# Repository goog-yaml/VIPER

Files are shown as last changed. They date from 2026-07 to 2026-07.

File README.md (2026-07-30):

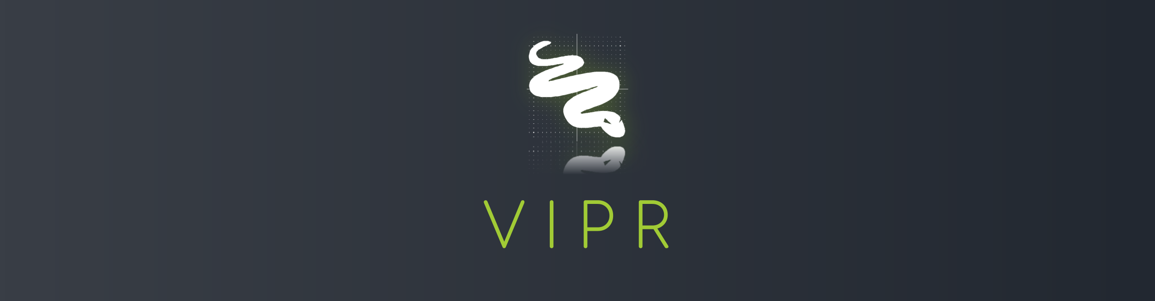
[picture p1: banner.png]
banner


# What is VIPR?

Simply put, VIPR is a open source radio node designed and built around North American mesh communication over LoRa built off of an ESP32-S3 platform. Put less simply, VIPR is another ESP32 development board focused more on frontend, hardware, and size. The project aims to create a small, pocketable radio node that can run independently. Currently the procsessing power of it's latest version (2.0) can only handle small workloads and can only run a Real Time OS in comparison to a fully fledged computer.

**VIPR is currently in Alpha testing, soon to be beta!**

## Current Revision

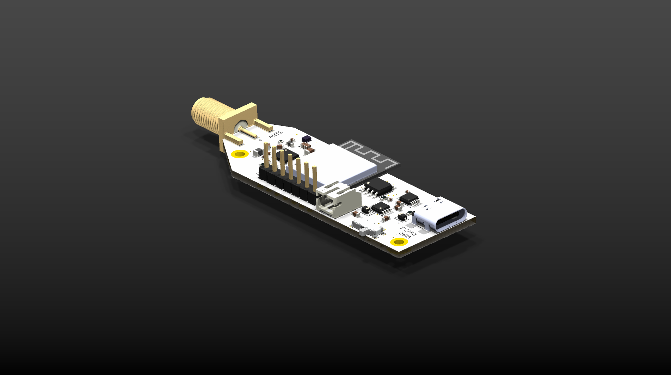
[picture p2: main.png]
Render1


Currently the board packs a 19mm wide footprint without a screen. The end is equipped with an SMA conector for easy antenna swaps and the side boasts an onboard PCB wifi antenna tied to the ESP32-MINI-1 module.

Future revisions intend to add a screen and interactives to the board to further refine the frontend, all that is needed after that is software and a case!

### Changelog

```
* Redid a proper BOM
    * This included sizing and components selection
* Added back the CH340X
* Reverted to old "pen" form factor
* Created a new "lopsided" board end 
* Added a screen header
* Fixed a regulator issue on the radio portion
* bundled CAD files into production folders <=2.1
```

## Docs

Docs will be coming soon!
<br>

## Versioning system

The project follows a versioning system of major and minor. The first number in the version is the board platform. Whenever the board is fully redone a new major version will be released. Whenever the board has a small tweak to an existing platform version the second number behind the first will be bumped up by one.

A board version of say, 2.1 would indicate platform version 2 with one tweak of the original version 2.0.

#### Latest Journal as of July 28th

For revision 2.1. I introduced a versioning system of major and minor.
 What's new in 2.1?

Mounting holes for M2 screws on the left side of the board and a header connection for a screen. the schematics now include test points for serial, power, and JTAG soon to be onboard for revision 2.2.

Some issues were included in revision 2 that would prevent stable operation of the radio caused by a faulty connection between the regulator for the SX1262 and the inductor managing it.

That's all.

-Matias

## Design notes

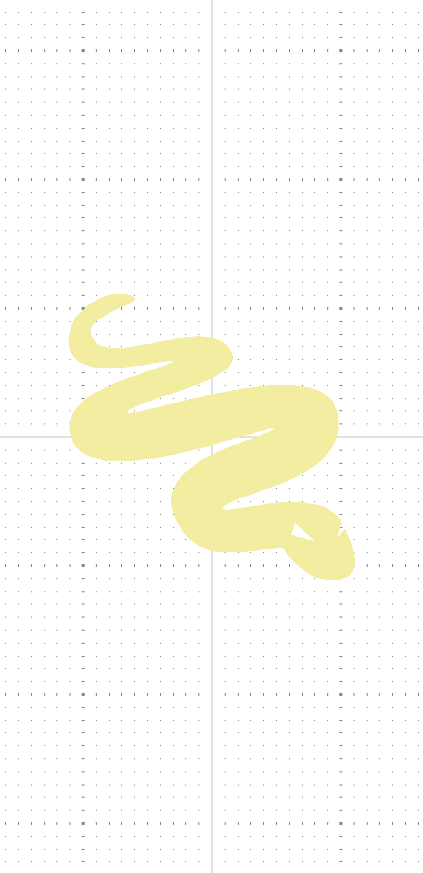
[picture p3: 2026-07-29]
KiCAD/main/viper.png

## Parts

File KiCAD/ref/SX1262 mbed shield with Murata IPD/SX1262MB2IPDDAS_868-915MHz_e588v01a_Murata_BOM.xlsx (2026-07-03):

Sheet: SX1262MB2IPDDAS
 |  |  | SX1262MB2IPDDAS mbed shield with IPD filter BOM - 868/915MHz |  |  | BOM # V1a
 |  |  |  |  |  | SCH # e588v01a
 |  |  | 2025-11-11 | EMr | Version e588v01a | PCB # e588v01a
RefDes | MPN | Geom | Value | Qty | Description | Manufacturer
U1 | SX1262IMLTRT | VQFN24 4x4mm | SX1262 | 1 | 150MHz to 960MHz Low Power Long Range Transceiver | Semtech
U2 | BGS12WN6 | PG-TSNP-6-10 | - | 1 | Wideband SPDT Diversity Switch with Fast Switching Speed | Infineon
U3 | LFB21892MDZ7F957 | 2.00x1.25mm | 868/915MHz | 1 | 868/915MHz Miniature Impedance-matched Filter for SX1261/62 and LLCC68 optimized for US and EU +22 dBm Operation | Murata
Resistors
R1 | CRCW06030000Z0EAHP | 0603 | 0R | 1 | Thick Film Resistor ±1%, 1/4W | Vishay/Dale
R2 | CRCW06030000Z0EAHP | 0603 | 0R | 1 | Thick Film Resistor ±1%, 1/4W | Vishay/Dale
R3 | CRCW0201100RJNED | 0201 | 100R | 1 | Thick Film Resistor ±5%, 1/20W | Vishay/Dale
R4 | CRCW0201100RJNED | 0201 | 100R | 1 | Thick Film Resistor ±5%, 1/20W | Vishay/Dale
R5 | CRCW02013K30JNED | 0201 | 3.3k | 1 | Thick Film Resistor ±5%, 1/20W | Vishay/Dale
R6 | CRCW02013K30JNED | 0201 | 3.3k | 1 | Thick Film Resistor ±5%, 1/20W | Vishay/Dale
R18 | CRCW04020000Z0ED | 0402 | 0R | 1 | Thick Film Resistor ±1%, 1/16W | Vishay/Dale
R868 | CRCW04020000Z0ED | 0402 | 0R | 1 | Thick Film Resistor ±1%, 1/16W | Vishay/Dale
R915 | CRCW04020000Z0ED | 0402 | 0R | 1 | Thick Film Resistor ±1%, 1/16W | Vishay/Dale
SX1262 | CRCW040210K0FKED | 0402 | 10k | 1 | Thick Film Resistor ±1%, 1/16W | Vishay/Dale
FR1 | CRCW040210K0FKED | 0402 | 10k | 1 | Thick Film Resistor ±1%, 1/16W | Vishay/Dale
XTAL | CRCW04020000Z0ED | 0402 | 0R | 1 | Thick Film Resistor ±1%, 1/16W | Vishay/Dale
Capacitors
C1 | GRM033R61C473KE84D | 0201 | 47nF | 1 | Multilayer ceramic capacitors X5R ±10%, 16V | Murata
C2 | GRM0335C1H470JA01D | 0201 | 47pF | 1 | Multilayer ceramic capacitors COG ±5%, 50V | Murata
C8 | GRM0335C1H390JA01D | 0201 | 39pF | 1 | Multilayer ceramic capacitors COG ±5%, 50V | Murata
C9 |  | 0201 | NC | 0 |  | Murata
C10 |  | 0201 | NC | 0 |  | Murata
C14 | GRM033R71H102KA12D | 0201 | 1nF | 1 | Multilayer ceramic capacitors X7R ±10%, 50V | Murata
C15 | GRM033R71H102KA12D | 0201 | 1nF | 1 | Multilayer ceramic capacitors X7R ±10%, 50V | Murata
C16 | GRM155R61E105KA12D | 0402 | 1uF | 1 | Multilayer ceramic capacitors X5R ±10%, 10V | Murata
C17 | GRM155R61A474KE15D | 0402 | 470nF | 1 | Multilayer ceramic capacitors X5R ±10%, 10V | Murata
C18 | GRM033R61A104KE15D | 0201 | 100nF | 1 | Multilayer ceramic capacitors X5R ±10%, 10V | Murata
C20 | GRM188R61A105KA61D | 0603 | 1uF | 1 | Multilayer ceramic capacitors X5R ±10%, 10V | Murata
C21 | GRM188R61A105KA61D | 0603 | 1uF | 1 | Multilayer ceramic capacitors X5R ±10%, 10V | Murata
C22 | GRM188R61A106KE69D | 0603 | 10uF | 1 | Multilayer ceramic capacitors X5R ±10%, 10V | Murata
C23 | GRM033R61A104KE15D | 0201 | 100nF | 1 | Multilayer ceramic capacitors X5R ±10%, 10V | Murata
Inductors & Ferrites
L1 | LQW15AN47NJ00D | 0402 | 47nH | 1 | Wirewound Inductor ±5% | Murata
L5 | CRCW02010000Z0ED | 0201 | 0R | 1 | Thick Film Resistor ±5%, 1/20W | Murata
L7 | MLZ2012M150W | 0805 | 15uH | 1 | MLZ2012 Multilayer Shielded Inductor ±5% | TDK
or (2nd source) | MLZ1608N100LT000 | 0603 | 10uH | 1 | MLZ1608 Multilayer Shielded Inductor ±20% | TDK
or (2nd source) | MLZ1608N150LT000 | 0603 | 15uH | 1 | MLZ1608 Multilayer Shielded Inductor ±20% | TDK
L8 |  | 0402 | 47nH | 0 |  | Murata
Crystal & TCXO
Q1 | EXS00A-CS06465 | NX2016SA 2.0x1.6mm | 32.000MHz | 1 | Crystal unit NDK; Tol. ±10ppm, Cload=10pF, G-Senstivity=2ppb/G max | NDK
or | FTR5123-A0 | QESM09 2.0x1.6mm | 32.000MHz | - | Crystal unit Rakon; Tol. ±10ppm, Cload=10pF, G-Senstivity=2ppb/G max | Rakon
Connectors and others (or P/N equivalent)
ANT | 142-0701-841 | SMA End Launch | 50 Ohms | 1 | SMA End launch jack receptacle for PCB mount for 1.00mm PCB thickness | Cinch Connectivity Sol Johnson
J1 | 68000-108HLF | Header 1x8 | 8 pins | 1 | 8 Pins - Through hole single row male connector, Bottom side | FCI
J2 | 68000-110HLF | Header 1x10 | 10 pins | 1 | 10 Pins - Through hole single row male connector, Bottom side | FCI
J3 | 68000-108HLF | Header 1x8 | 8 pins | 1 | 8 Pins - Through hole single row male connector, Bottom side | FCI
J4 | 68000-106HLF | Header 1x6 | 6 pins | 1 | 6 Pins - Through hole single row male connector, Bottom side | FCI
ANA_A5_A6 | 1125S-4P | 4-pin - Grove | 4 pins | 0 | 2mm pitch - Grove universal 4-pin connector for sensor (SKU: 320110033), Top side | Shenzhen NS-Tech
DIO_D9_D10 | 1125S-4P | 4-pin - Grove | 4 pins | 0 | 2mm pitch - Grove universal 4-pin connector for sensor (SKU: 320110033), Top side | Shenzhen NS-Tech
I2C | 1125S-4P | 4-pin - Grove | 4 pins | 0 | 2mm pitch - Grove universal 4-pin connector for sensor (SKU: 320110033), Top side | Shenzhen NS-Tech
Additional or optional components
- | BMI-S-209-F | Shield | - | 0 | Standard Surface Mount Shield in two parts with BMI-S-209-C cover (optional) | Laird Technologies
Remark: components not listed in the BOM or 0 quantity, are not populated on the module.

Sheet: Release
 |  | SX1262MB2IPDDAS mbed shield with IPD filter BOM - 868/915MHz |  |  |  | BOM # V1a
 |  |  |  |  |  | SCH # e588v01a
 |  | 2025-11-11 | EMr | Version e588v01a |  | PCB # e588v01a
Release history
Version | Change notes |  |  |  | By
pcb_e588v01a | Module based on PCB_E499V01B with IPD filter. |  |  |  | EMr
 | Update BOM with P/N - 18.05.2020 |  |  |  | EMr
 | Update BOM @868/915MHz only with P/N - 22.02.2022 |  |  |  | EMr
 | Replacement of U2 RF switch with BGS12WN6 - 03.03.2025 |  |  |  | EMr
 | IPD Murata P/N updated |  |  |  | EMr

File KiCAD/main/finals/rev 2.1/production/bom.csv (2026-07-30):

Designator | Footprint | Quantity | Value | LCSC Part #
BT1 | JST_PH_S2B-PH-K_1x02_P2.00mm_Horizontal | 1 | Battery_Cell | C265094
C1, C2 | 0603 | 2 | 1uF | C15849
C10, C11, C17, C18, C3, C6, C7 | 0402 | 7 | 0.1uF | C1525
C12 | 0603 | 1 | 22 pF | C1653
C13 | 0402 | 1 | 100nF | C1525
C14, C15, C16 | 0603 | 3 | 10uF | C19702
C4 | 0805 | 1 | 22uF | C45783
C5 | 0603 | 1 | 470pF | C1620
D1, D2 | D_SOD-323 | 2 | D_Schottky | C191023
J1 | USB_C_Receptacle_GCT_USB4110 | 1 | USB_C_Receptacle_USB2.0_14P | C2765186
J2 | SMA_Amphenol_132289_EdgeMount | 1 | Conn_Coaxial | C3039673
J3 | PinHeader_1x07_P2.54mm_Vertical | 1 | Conn_01x07_Socket
L1 | 0805 | 1 | 15uH | C383402
L2 | 0603 | 1 | 18 nH | C19721138
R1, R2 | 0603 | 2 | 5K1 | C23186
R10, R4, R9 | 0603 | 3 | 10K | C25804
R5 | 0402 | 1 | 100R | C25076
R7 | 0603 | 1 | 1.2K | C22765
SW1 | SSSS810701 | 1 | SW_SPDT | C97433
U1 | QFN-24-1EP_4x4mm_P0.5mm_EP2.6x2.6mm | 1 | SX1262IMLTRT | C191341
U2 | SOIC-8-1EP_3.9x4.9mm_P1.27mm_EP2.41x3.3mm_ThermalVias | 1 | TP4056-42-ESOP8 | C16581
U3 | Infineon_PG-TSNP-6-10_0.7x1.1mm_0.7x1.1mm_P0.4mm | 1 | BGS12P2L | C3312945
U6 | MSOP-8_3x3mm_P0.65mm | 1 | MIC5219-3.3YMM | C628154
U7 | MSOP-10_3x3mm_P0.5mm | 1 | CH340X | C3035748

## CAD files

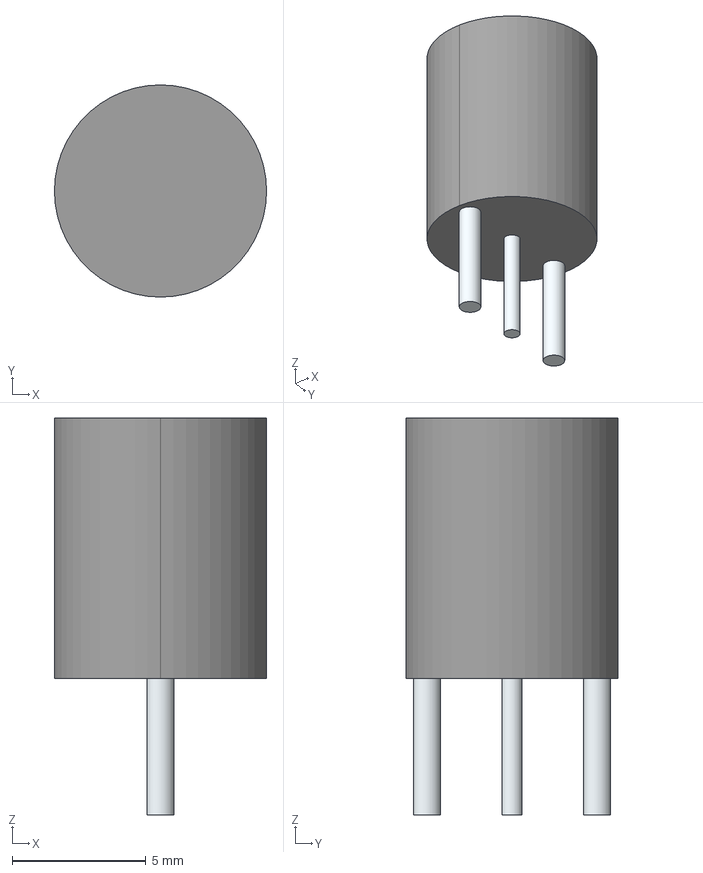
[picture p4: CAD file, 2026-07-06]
KiCAD/main/step/901-10040-1/3D/901-10040-1.stp
7.92 x 7.92 x 14.8 mm
Leads x 3

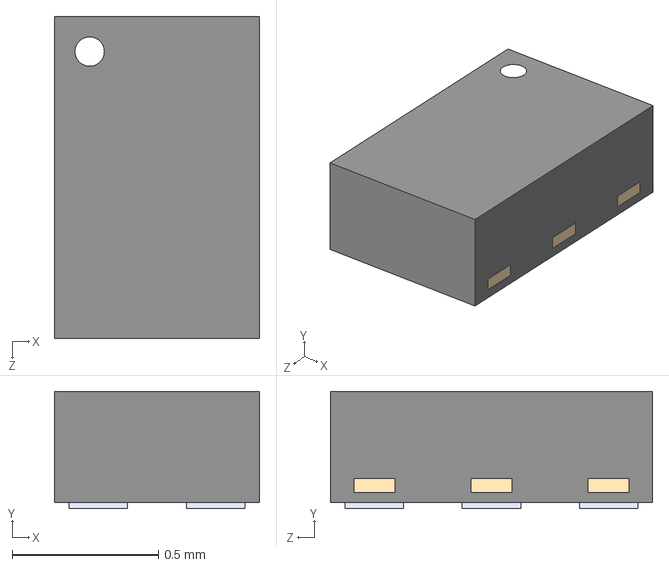
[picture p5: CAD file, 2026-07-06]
KiCAD/main/step/BGS12WN6E6327XTSA1/3D/BGS12WN6E6327XTSA1.stp
0.7 x 0.4 x 1.10 mm

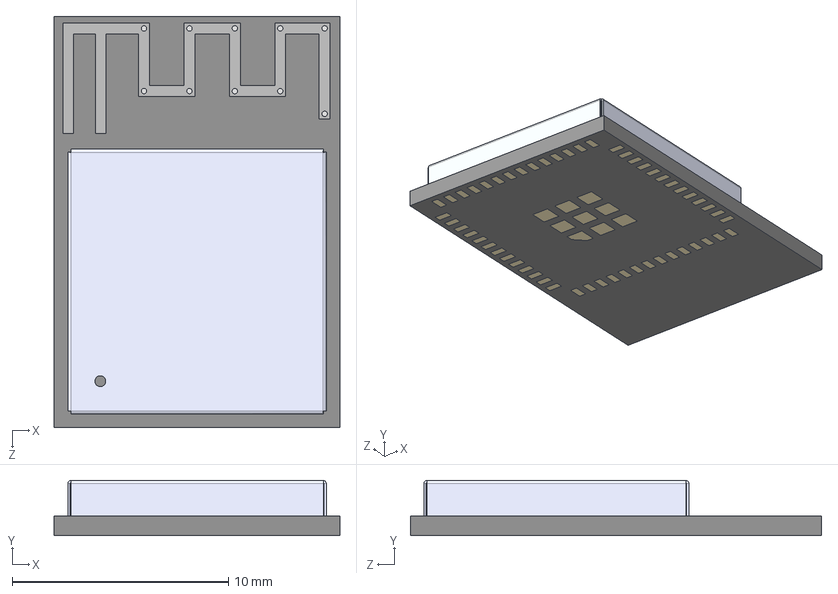
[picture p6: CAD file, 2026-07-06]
KiCAD/main/step/ESP32-MINI-1-H4/3D/ESP32-MINI-1-H4.stp
13.2 x 2.55 x 19.0 mm

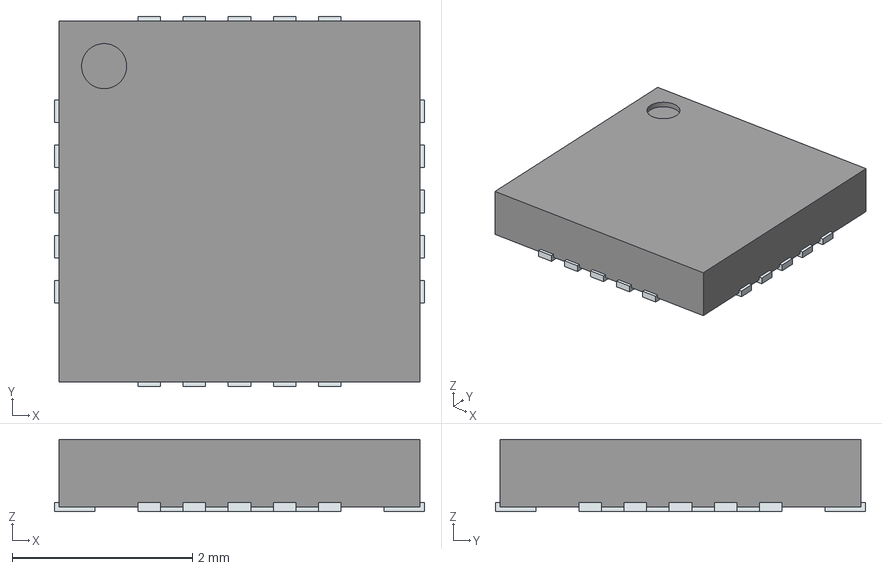
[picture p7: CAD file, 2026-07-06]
KiCAD/main/step/FT231XQ-R/3D/FT231XQ-R.stp
4.10 x 4.10 x 0.8 mm
ThermalPin
PinsArrayLR
PinsArrayTB

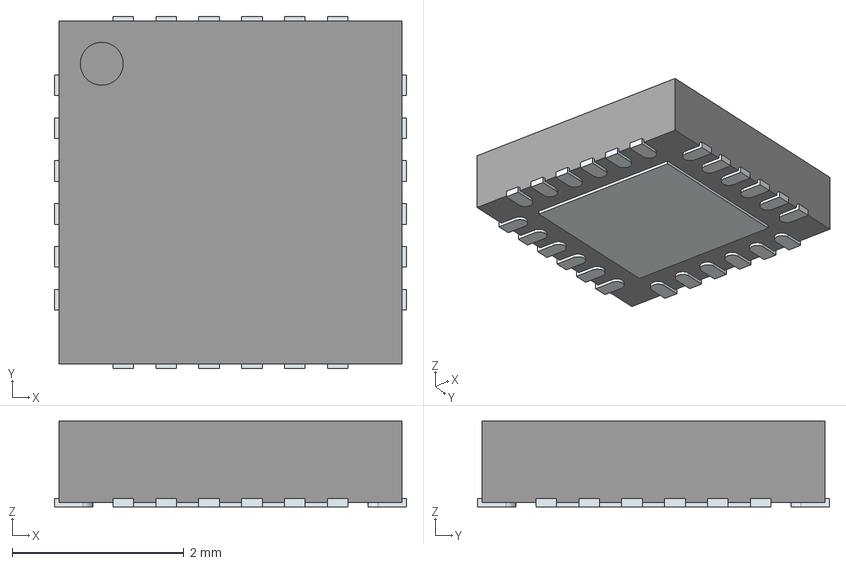
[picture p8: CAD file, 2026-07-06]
KiCAD/main/step/SX1262IMLTRT/3D/SX1262IMLTRT.stp
4.10 x 4.10 x 1.00 mm
ThermalPin
PinsArrayLR
PinsArrayTB

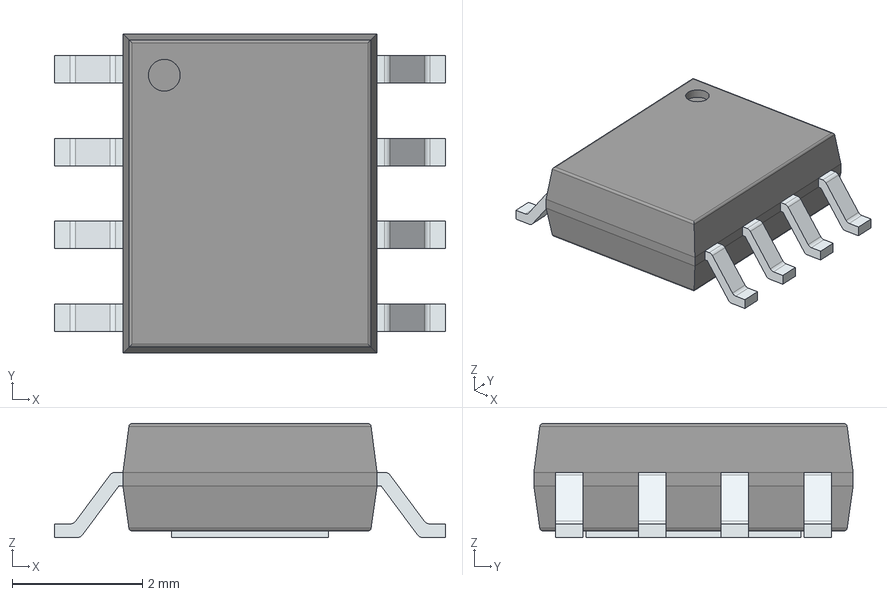
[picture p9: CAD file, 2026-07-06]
KiCAD/main/step/TP4056-42-ESOP8/3D/TP4056-42-ESOP8.stp
6.00 x 4.90 x 1.75 mm
PinsArrayLR
ThermalPad

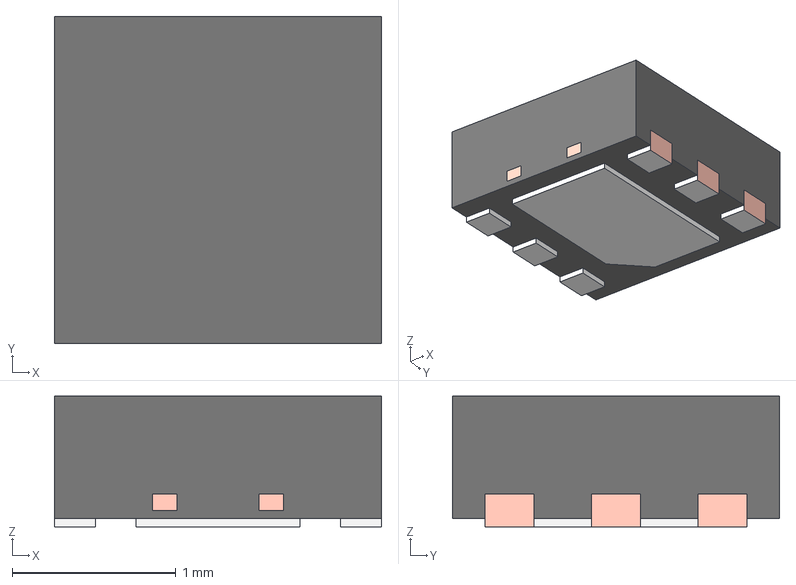
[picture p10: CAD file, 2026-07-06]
KiCAD/main/step/TLV75533PDRVR/3D/TLV75533PDRVR.stp
2.00 x 2.00 x 0.8 mm
BODY-SON
FRAME-DRV0006B
PIN1-ID

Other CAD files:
KiCAD/main/step/901-10040-1/Allegro/901100401.psm
KiCAD/main/step/901-10040-1/DEHDL/901_10040_1/chips/chips.prt
KiCAD/main/step/BGS12WN6E6327XTSA1/Allegro/bgs12wn6e6327xtsa1.psm
KiCAD/main/step/BGS12WN6E6327XTSA1/DEHDL/bgs12wn6e6327xtsa1/chips/chips.prt
KiCAD/main/step/ESP32-MINI-1-H4/Allegro/esp32mini1h4.psm
KiCAD/main/step/ESP32-MINI-1-H4/DEHDL/esp32_mini_1_h4/chips/chips.prt
KiCAD/main/step/FT231XQ-R/Allegro/qfn50p400x400x80-21n.psm
KiCAD/main/step/FT231XQ-R/DEHDL/ft231xq_r/chips/chips.prt
KiCAD/main/step/SX1262IMLTRT/Allegro/qfn50p400x400x100-25n-d.psm
KiCAD/main/step/SX1262IMLTRT/DEHDL/sx1262imltrt/chips/chips.prt
KiCAD/main/step/TLV75533PDRVR/Allegro/son65p200x200x80-7n.psm
KiCAD/main/step/TLV75533PDRVR/DEHDL/tlv75533pdrvr/chips/chips.prt
KiCAD/main/step/TP4056-42-ESOP8/Allegro/soic127p600x175-9n.psm
KiCAD/main/step/TP4056-42-ESOP8/DEHDL/tp4056_42_esop8/chips/chips.prt

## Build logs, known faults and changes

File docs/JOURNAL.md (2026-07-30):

---
Title: "VIPER"
Author: "Matias Argandona AKA Goog07,Goog-hash,Goog-yaml"
Description: "small side project to create the smallest meshtastic node system with multiple models ranging from large TX mast powerhouses to tiny iPod sized mobile nodes capable of running any open source large radio firmware"
Created_at: "2026-07-04"
---

# July 6th: Second revision

Today I redid the board again, following my normal routine redo to get the size smaller and smaller.

Rev1 was large and rev1.1 adopted a stick like shape while rev1.2 got wider by around 2 mm but a lot shorter.  

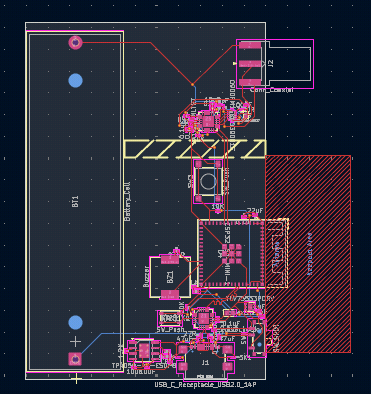
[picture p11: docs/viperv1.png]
revision1
<br>
As seen here Revision one is very big, with that LiPo holder on board a lot of the footprint is dedicated to that and that only. Making it very clunky for it's intended purpose.  

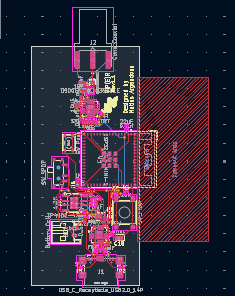
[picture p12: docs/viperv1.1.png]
revision1.1
<br>
Revision 1.1 fixes this by adding a two pin JST connector to save space with the added complexity of now needing to find the correct battery and tuning the board for it. And also the extra connectors adds more complexity requiring another component to be on the edge.  <br>

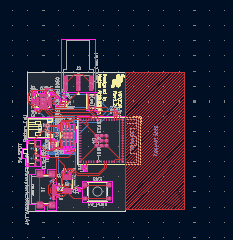
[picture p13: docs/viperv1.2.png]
revision1.2
<br>
Revision 1.2 fixes the issue of the USB serial chip and mitigates a possible manufacturing issue considering the chip used (FTDI FT231XQ) is outdated and expesive. To combat this I replaced the old IC with a new CH340X that has less pins and an arguably easier to work with MSOP-10 package. The package does come with gullwing pins, now most people would think of this as a size increase but considering my (questionable) soldering skills I consider it a pro.  

So far the project seems to be going good, I think I'm going to split this repo for different models of VIPER. See you!  

-Matias =)

[Total time spent: 48 mins]

# July 22nd: Brushing dust off this

I'm running up to add an addon system for the device and some dedicated pins to do so. as getting this from another really cool project called pocketbyte, go check it out!

I changed all of the LEDs to soft switches instead because i felt it looked nice.

I'm currently going to source a ref for the pinout soon. But It's going good.

- Matias

# July 28th

I just finished rev2 for the board! What's new?

I fixed the issue of all the passive components being 0402 metric then I decided to learn about hwo to pick the correct sizes for each component.

The CH340X is back in the board to allow USB serial and I'm thinking about adding JTAG headers to the board for debugging.

I went back to the pen form factor and also am considering adding a screen to the board.

There will be not more motive changes for now and the project will stay like this.

I'm going to continue to work on this and I think I'm going to get this produced

# July 30th: Added a screen and mounting holes

For revision 2.1. I introduced a versioning system of major and minor.
 What's new in 2.1?

Mounting holes for M2 screws on the left side of the board and a header connection for a screen. the schematics now include test points for serial, power, and JTAG soon to be onboard for revision 2.2.

Some issues were included in revision 2 that would prevent stable operation of the radio caused by a faulty connection between the regulator for the SX1262 and the inductor managing it.

That's all.

-Matias

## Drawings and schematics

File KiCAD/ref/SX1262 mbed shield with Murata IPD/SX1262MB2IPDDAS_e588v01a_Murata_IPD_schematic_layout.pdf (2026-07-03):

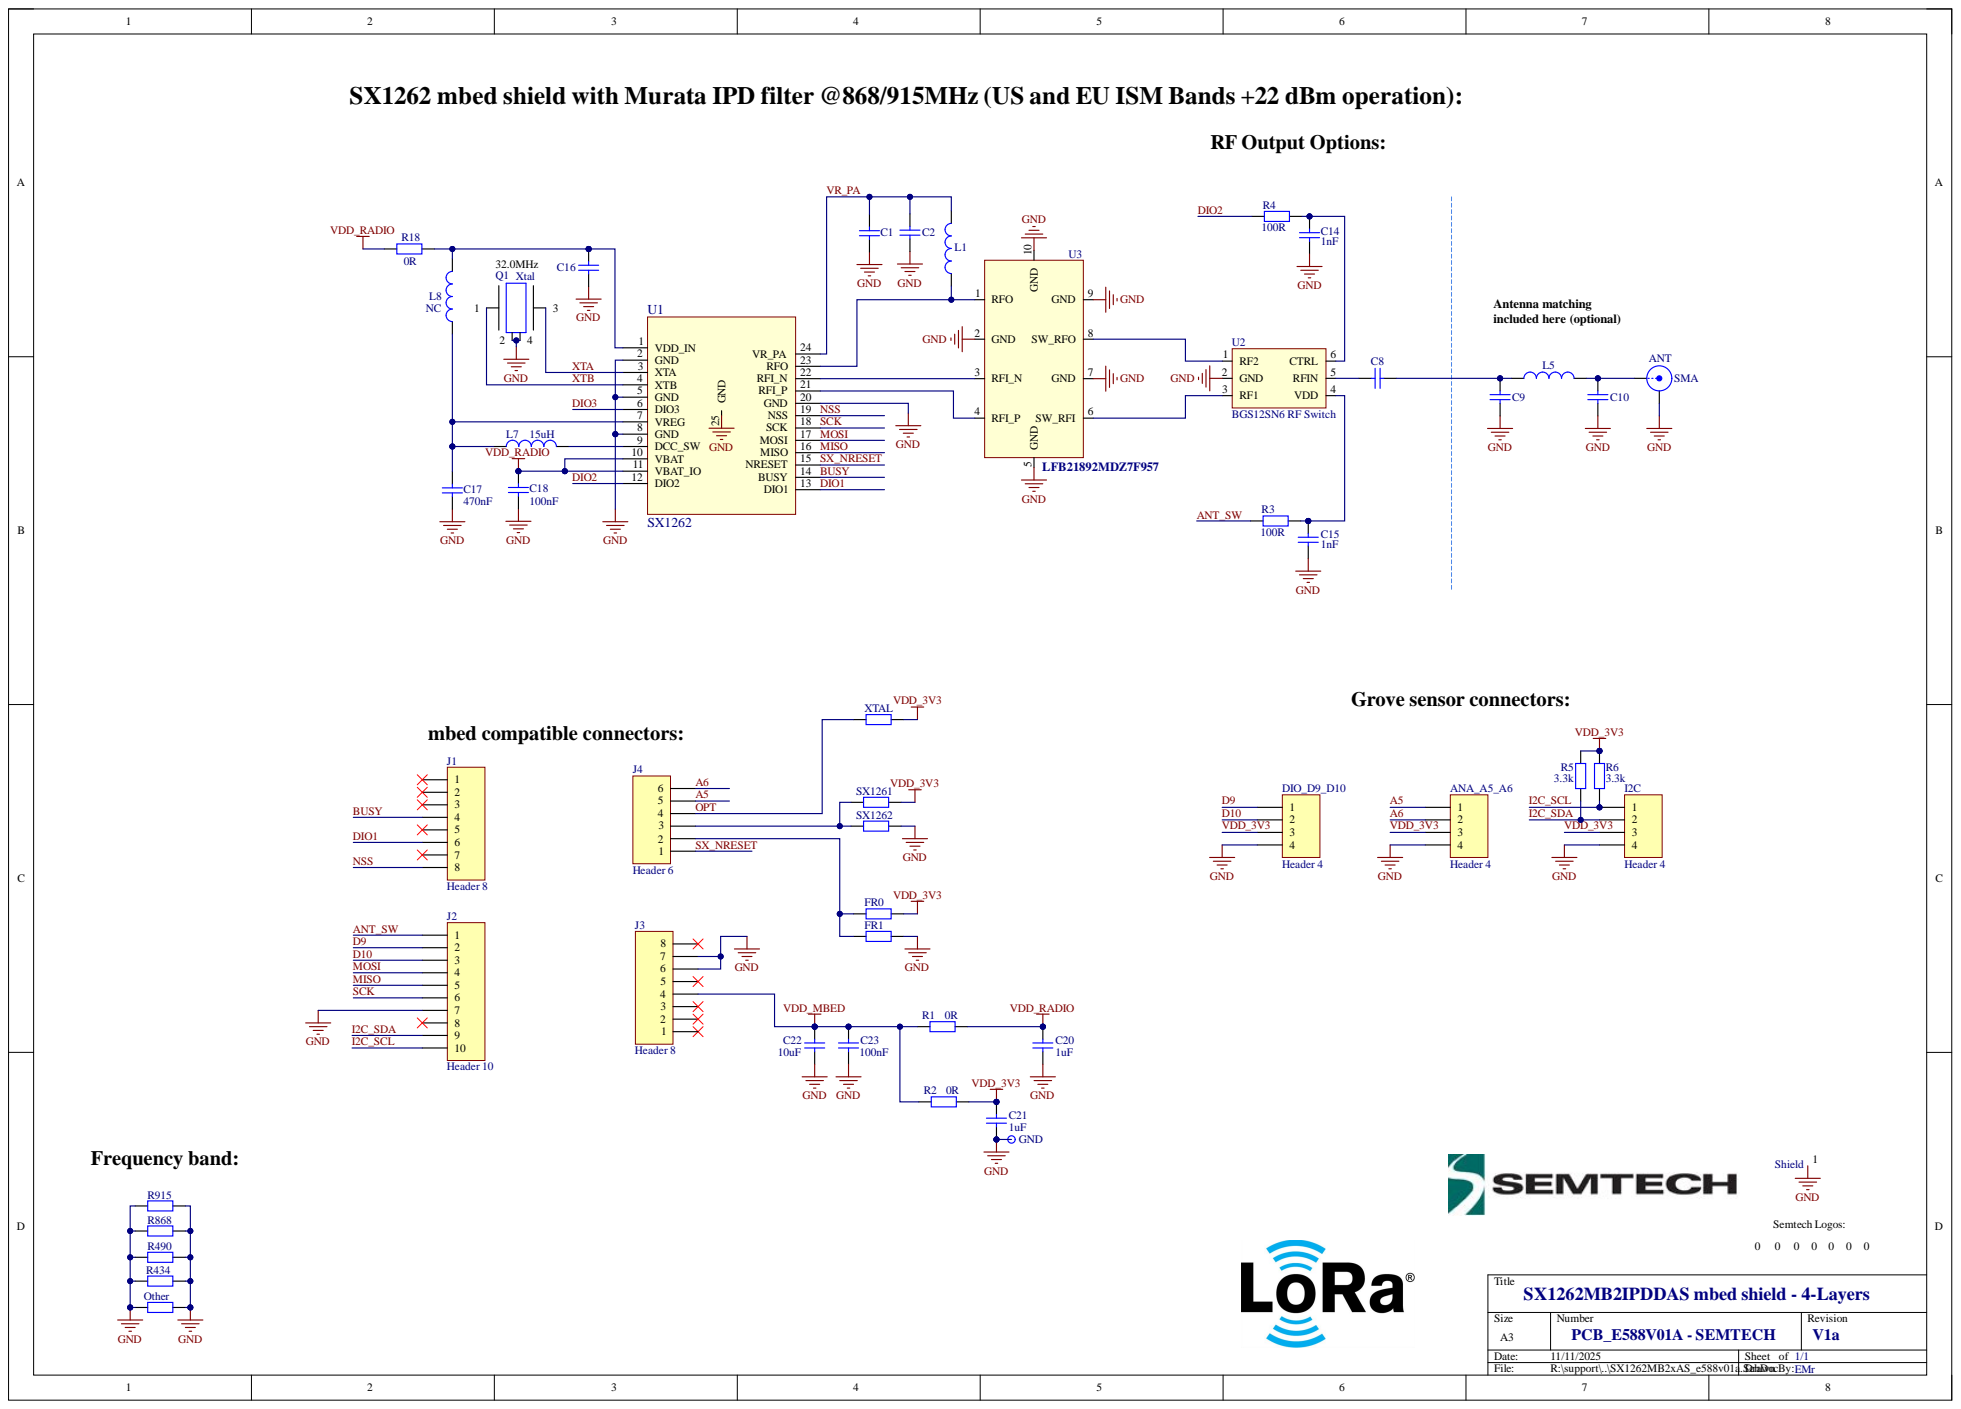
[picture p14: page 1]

SX1262 mbed shield with Murata IPD filter @868/915MHz (US and EU ISM Bands +22 dBm operation):

GND

DIO2 12 | BUSY

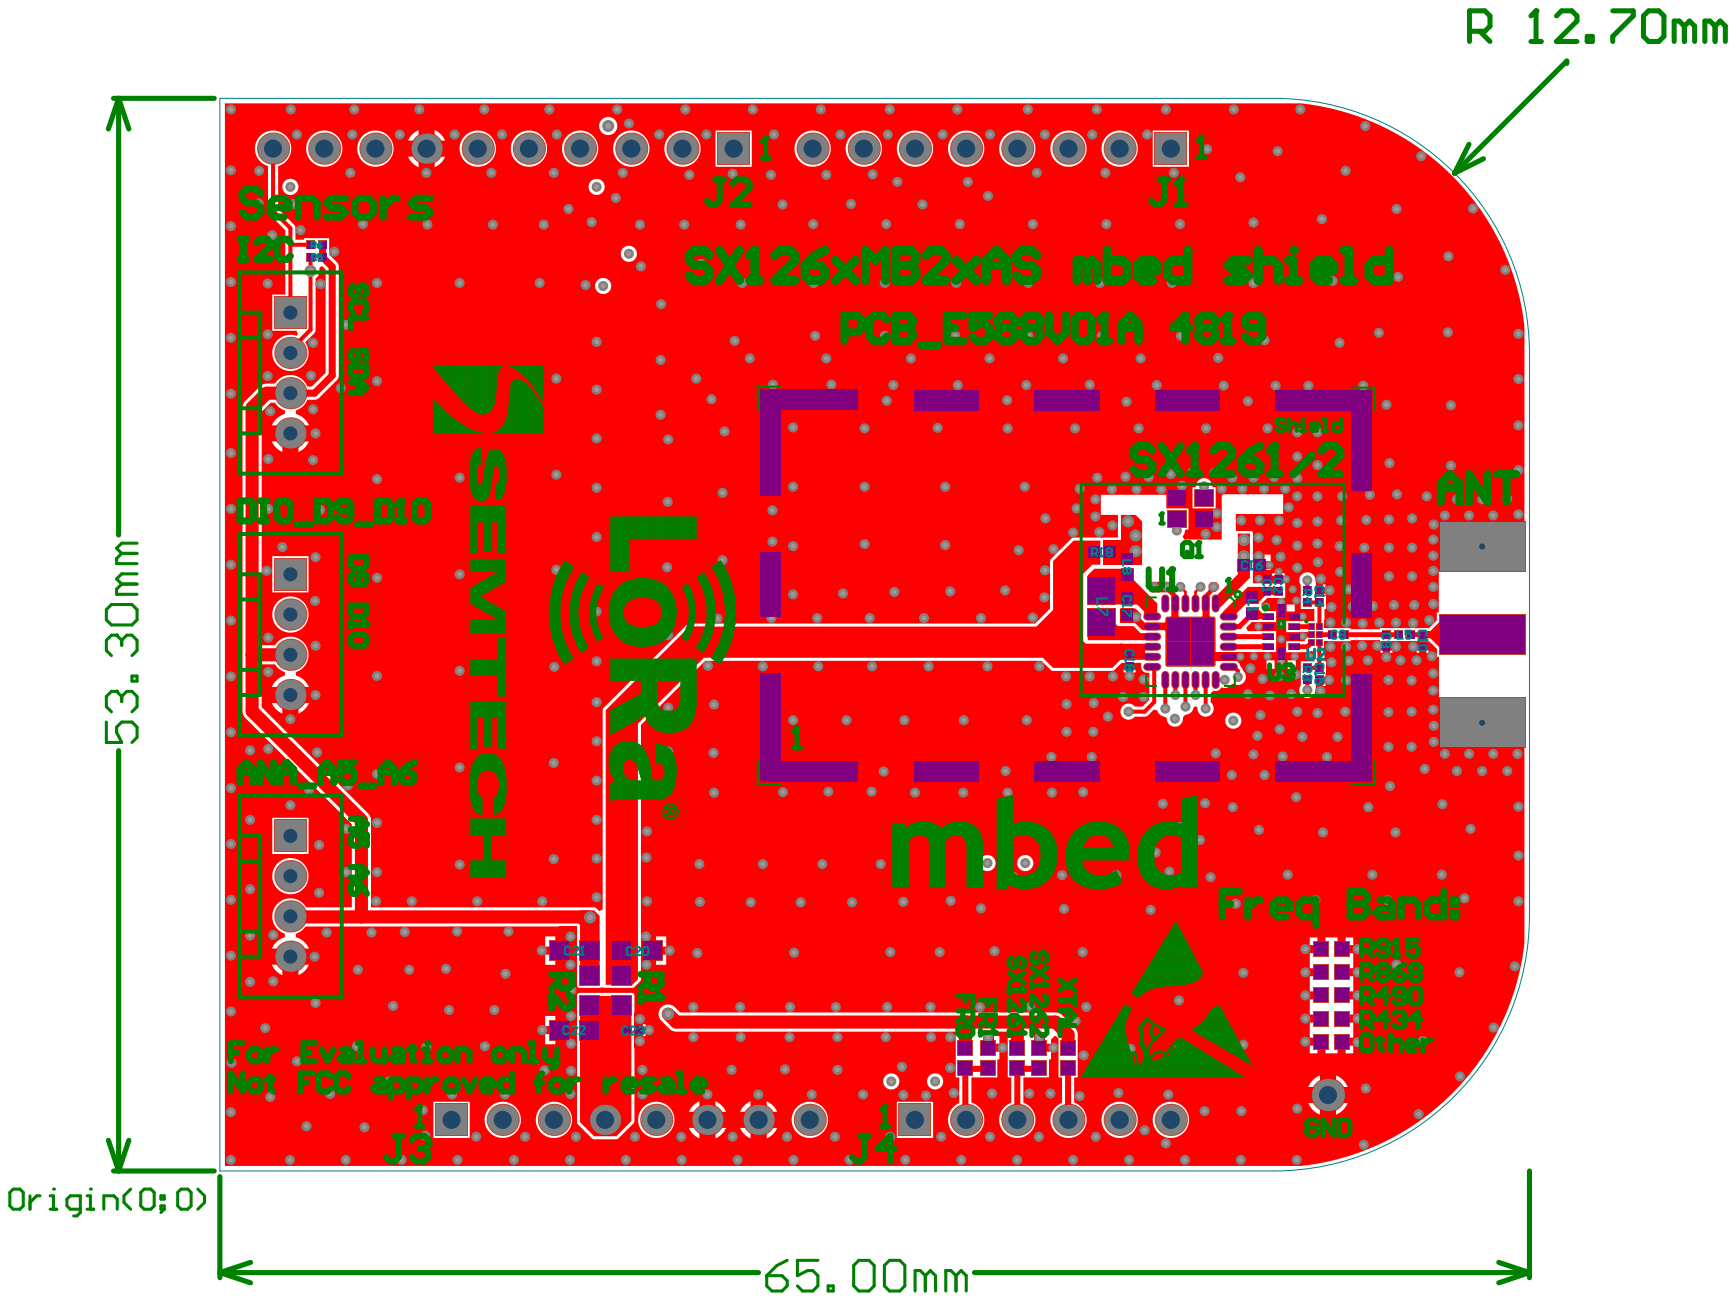
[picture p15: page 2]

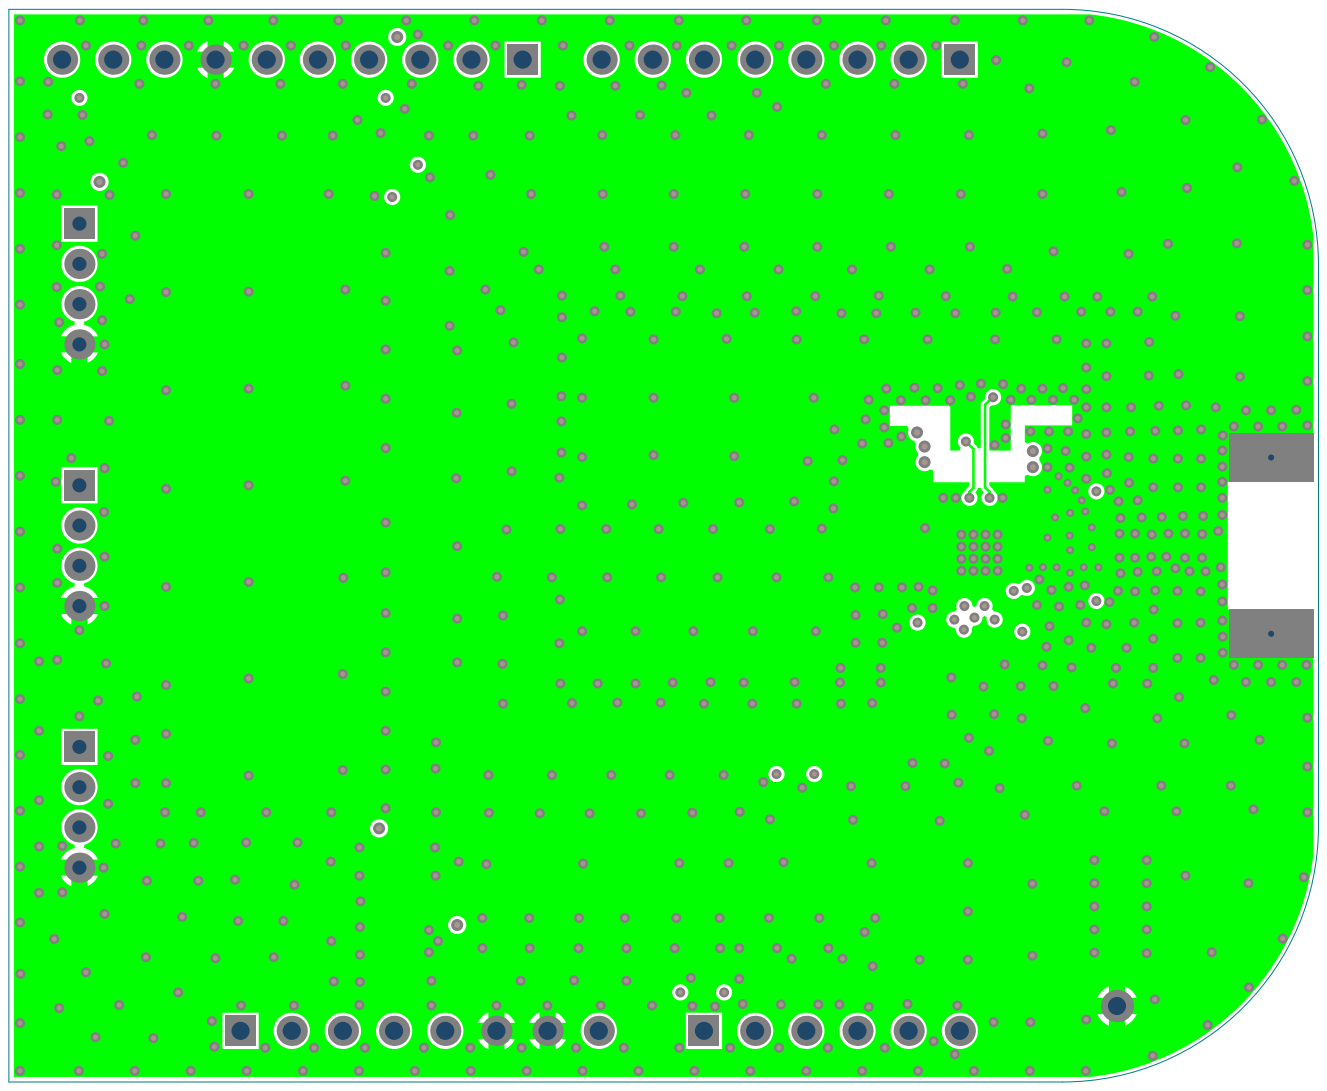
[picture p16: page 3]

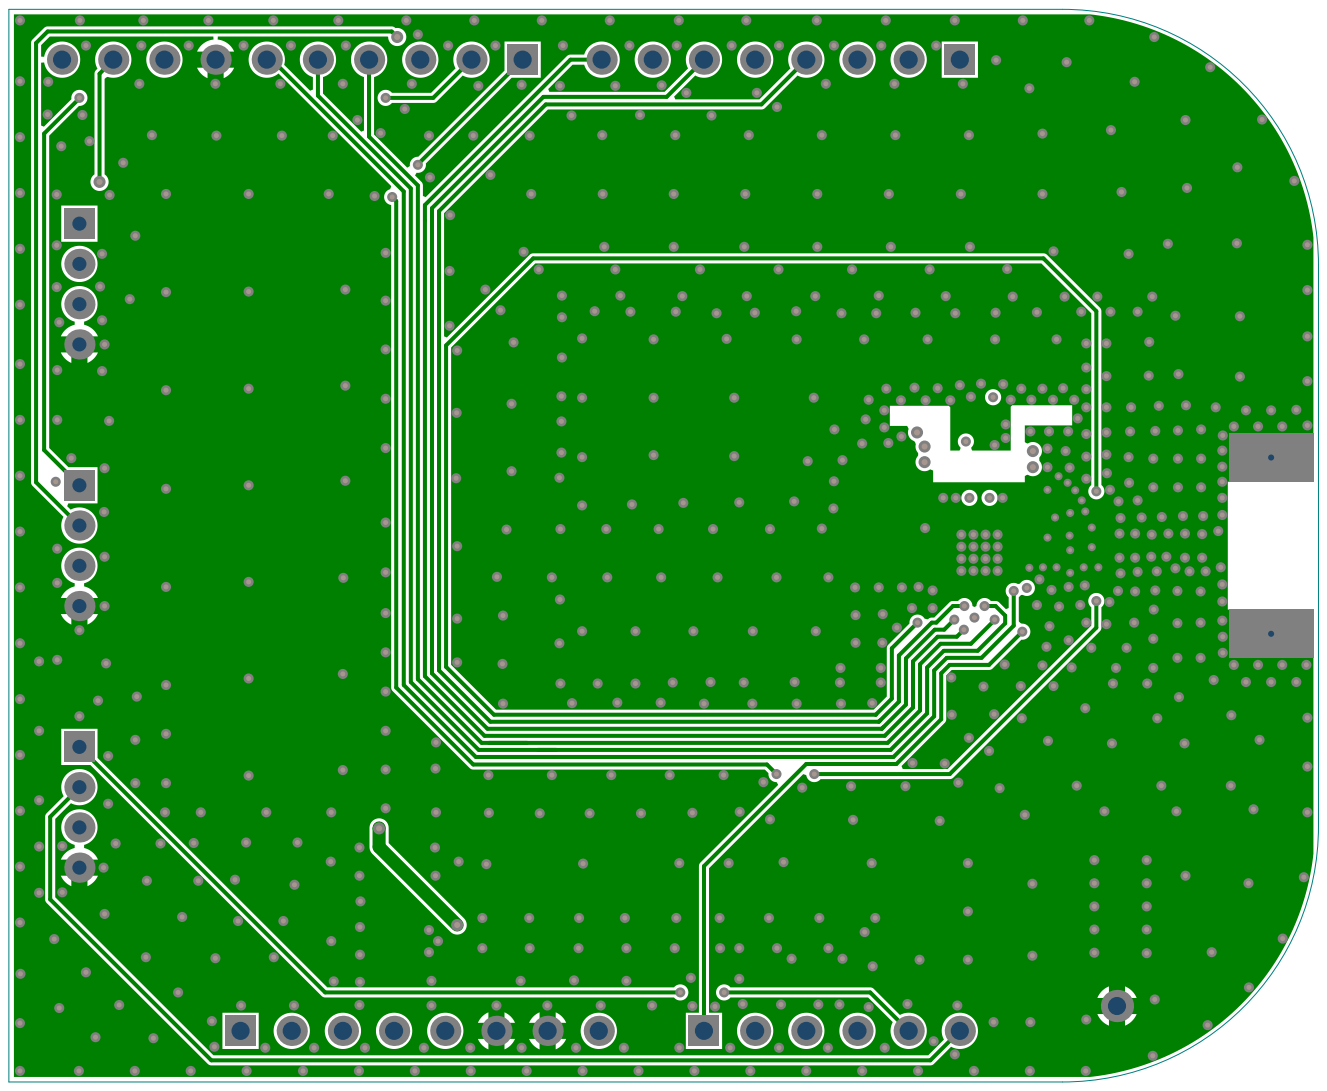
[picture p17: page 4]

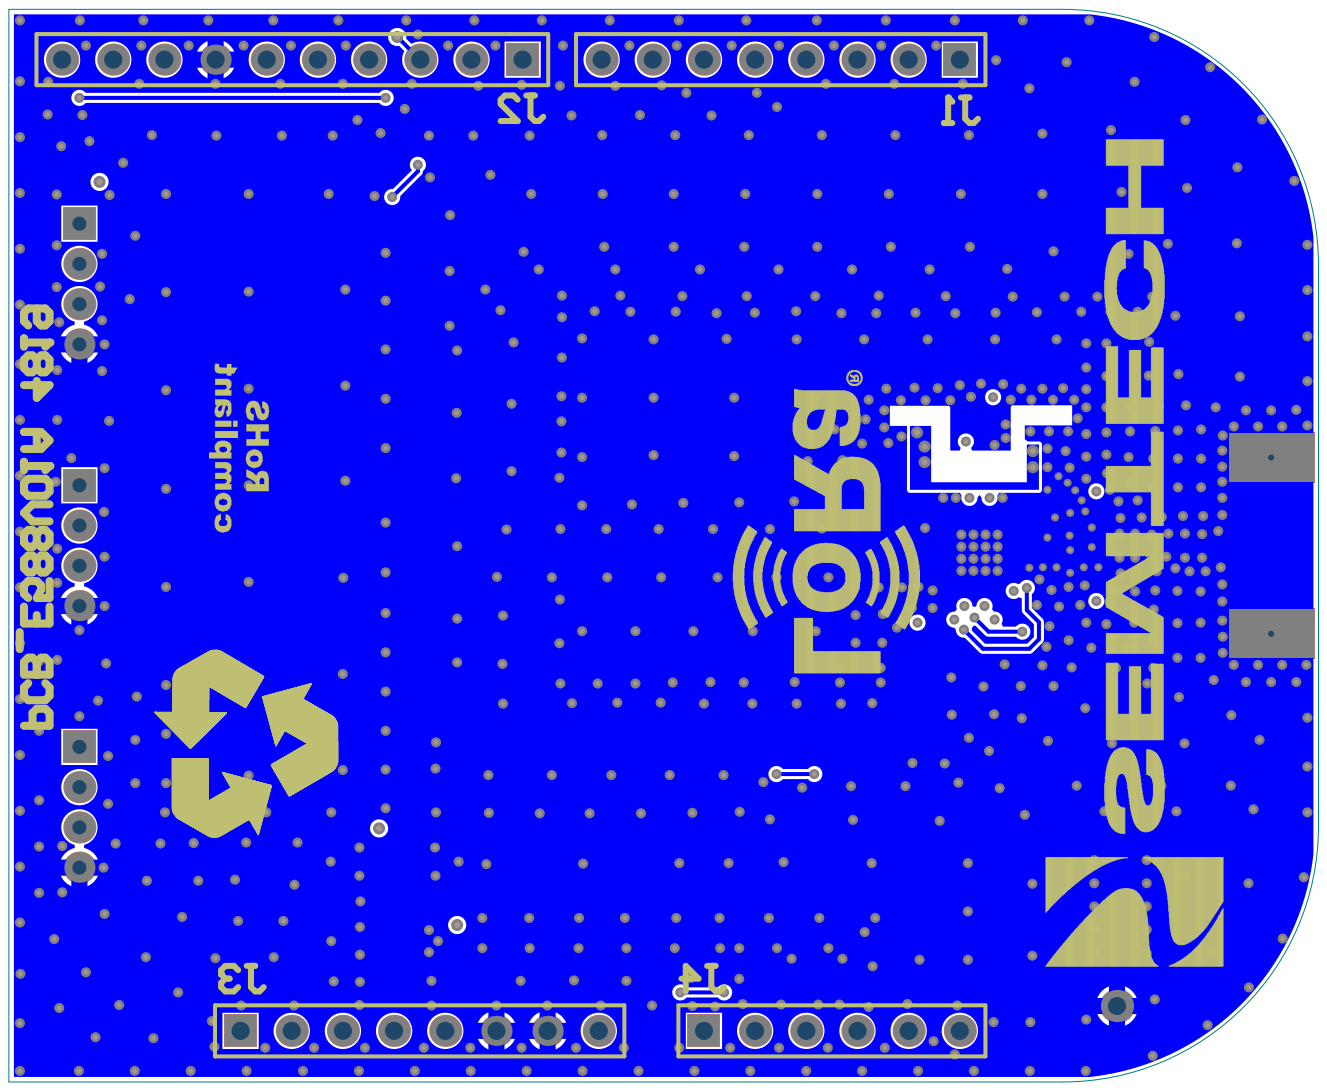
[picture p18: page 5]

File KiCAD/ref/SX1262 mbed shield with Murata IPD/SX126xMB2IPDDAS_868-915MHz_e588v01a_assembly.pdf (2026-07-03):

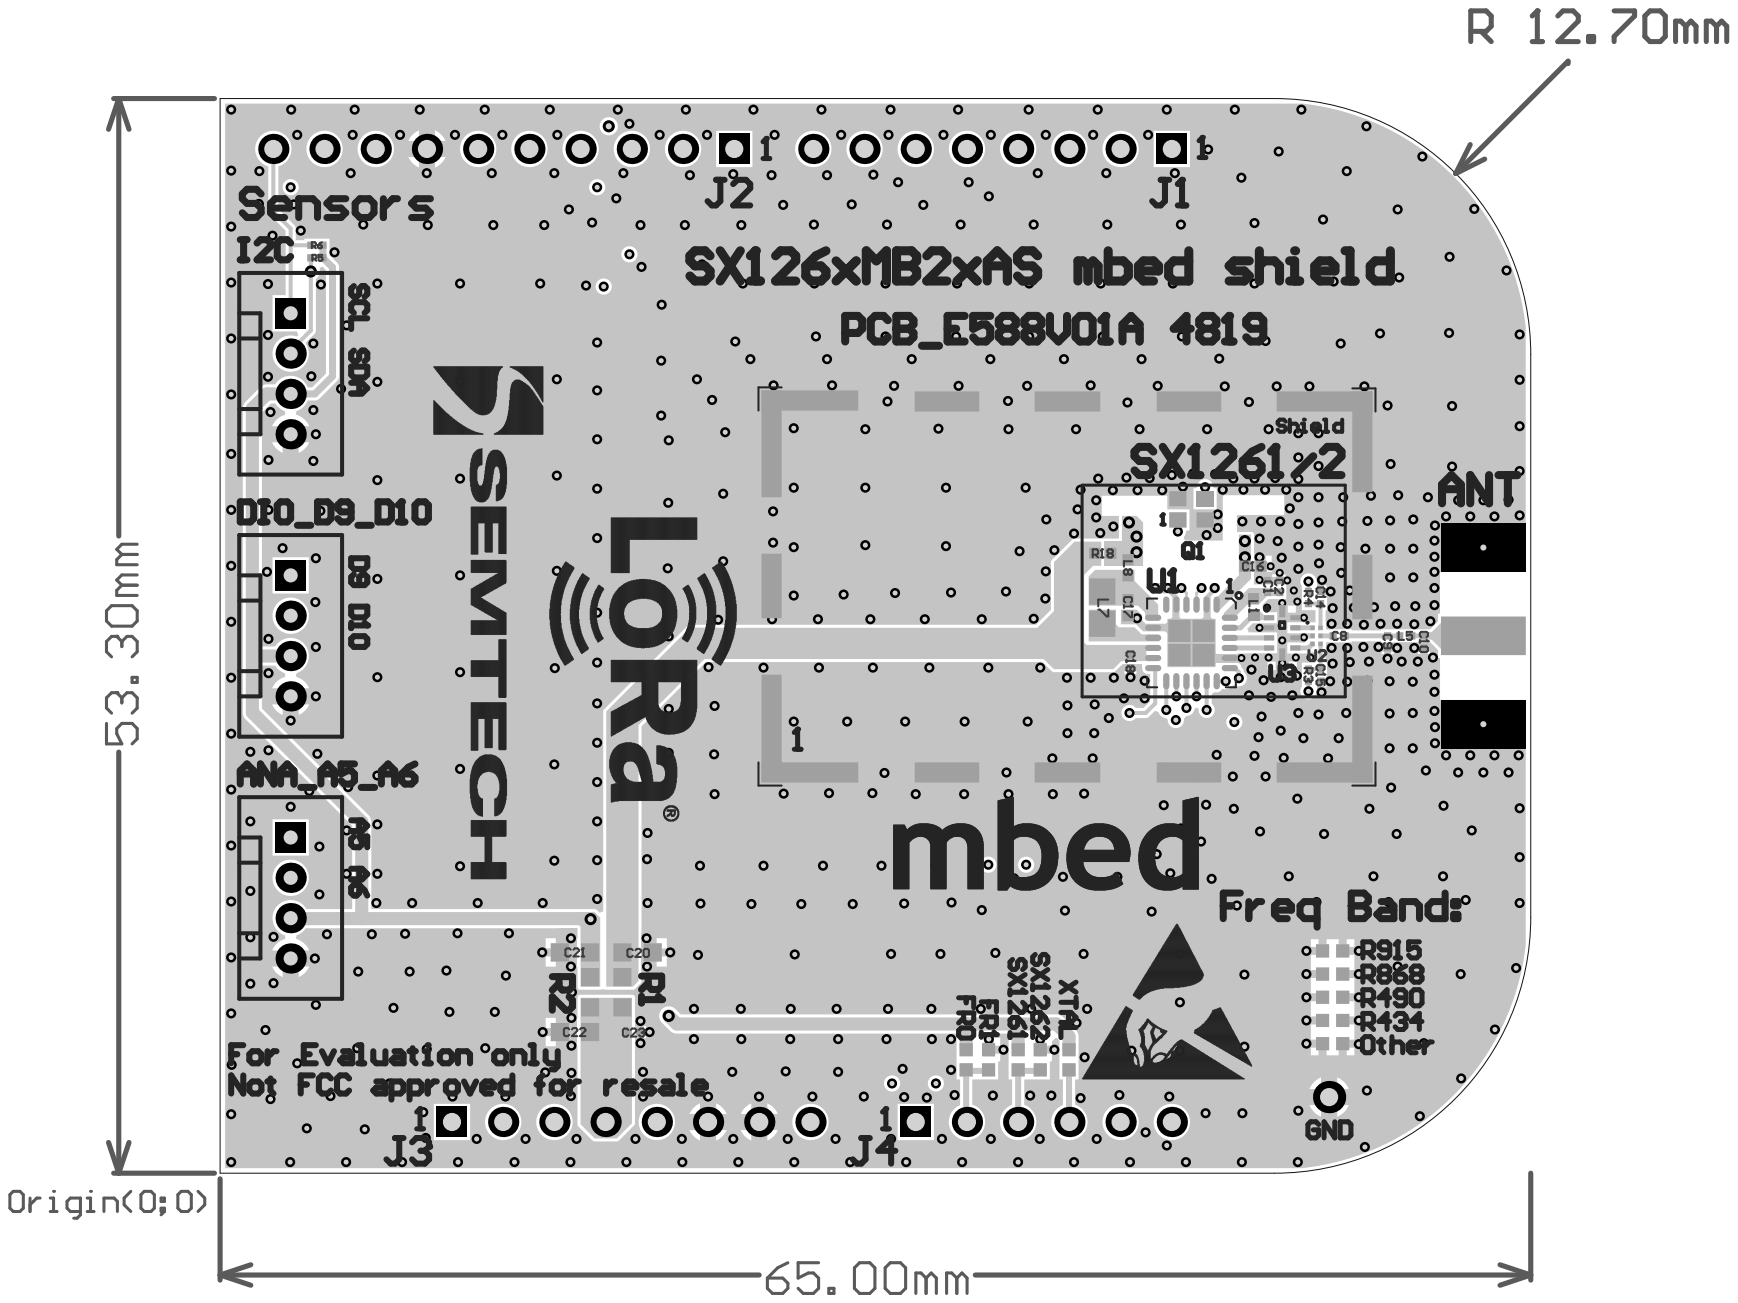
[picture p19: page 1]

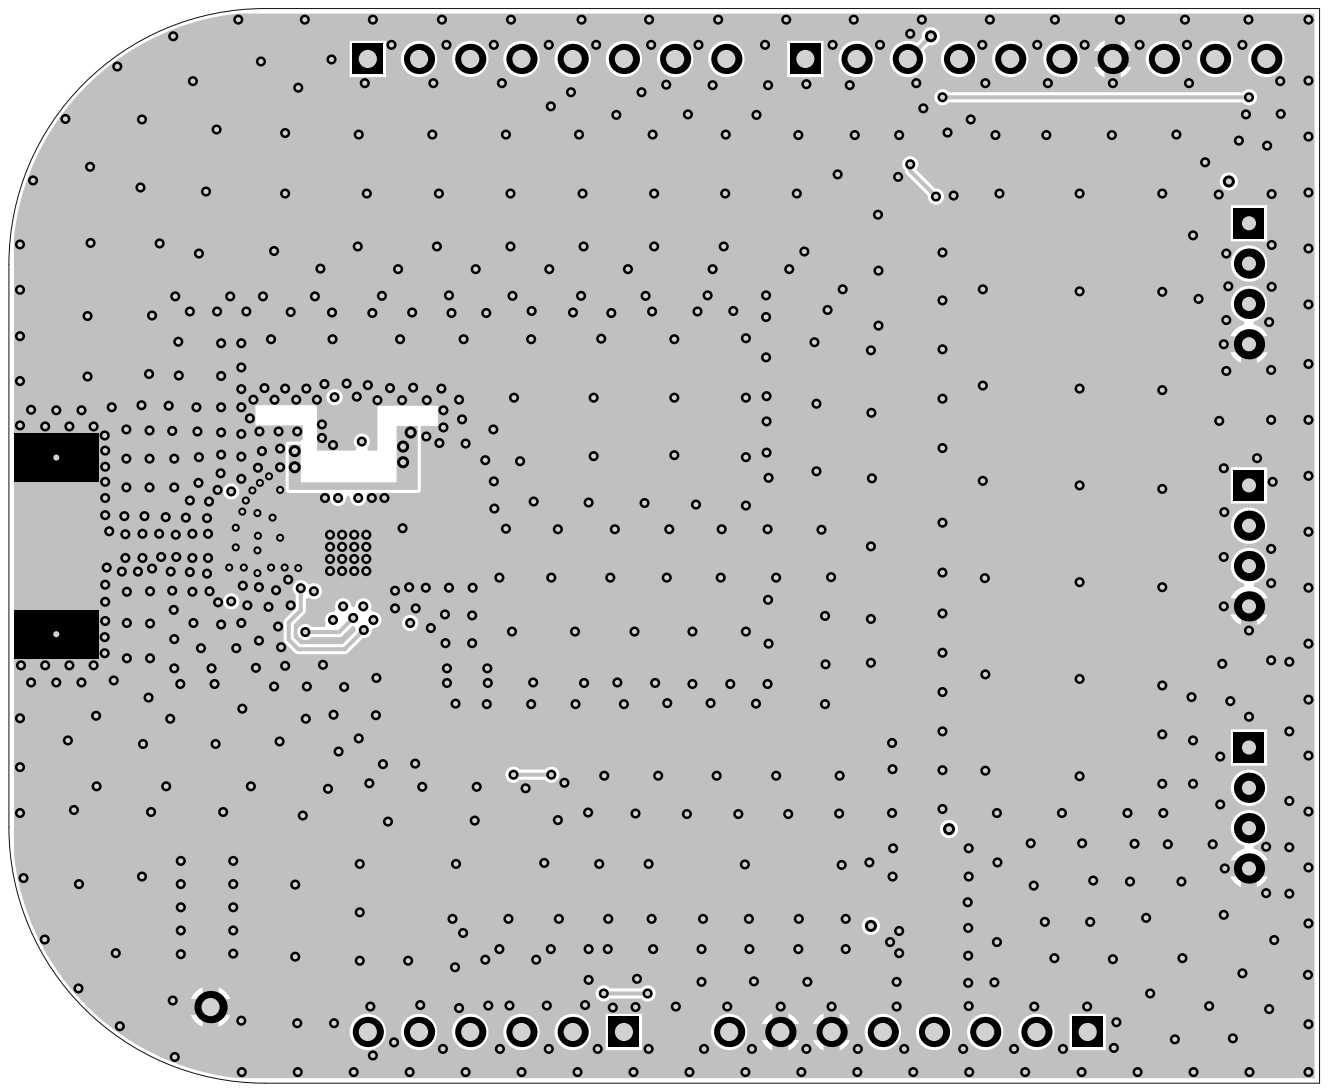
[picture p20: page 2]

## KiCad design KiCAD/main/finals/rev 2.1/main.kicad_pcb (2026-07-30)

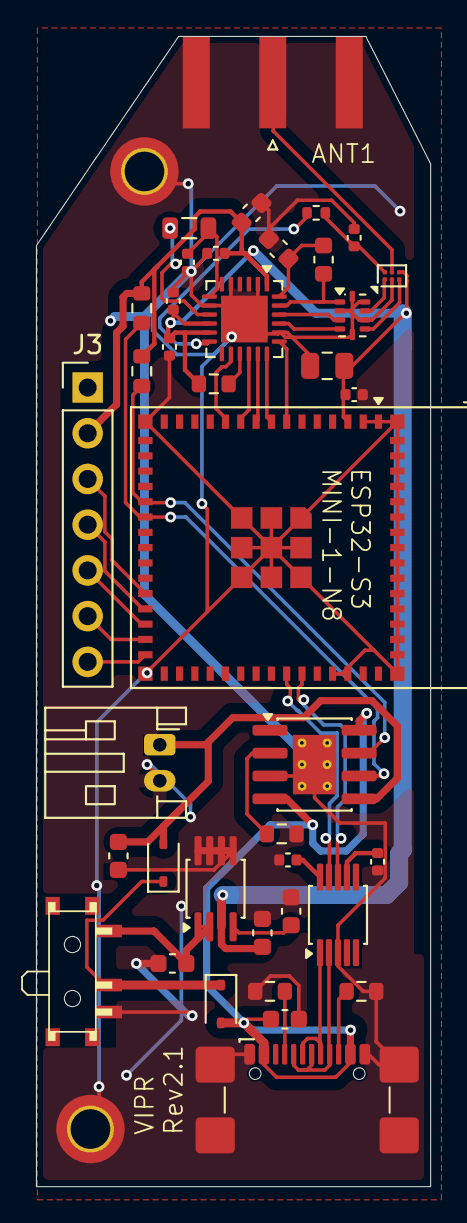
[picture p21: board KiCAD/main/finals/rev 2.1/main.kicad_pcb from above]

Board: 2 copper layers, 21.9 x 63.9 mm, 41 parts (0 on the bottom side), 38 nets.

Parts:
BT1: Battery_Cell; JST_PH_S2B-PH-K_1x02_P2.00mm_Horizontal
C1, C2: 1uF; C_0603_1608Metric
C3: 0.1uf; C_0402_1005Metric
C4: 22uF; C_0805_2012Metric
C5: 470pF; C_0603_1608Metric
C6, C7, C10, C11, C17, C18: 0.1uF; C_0402_1005Metric
C12: 22 pF; C_0603_1608Metric
C13: 100nF; C_0402_1005Metric
C14, C15, C16: 10uF; C_0603_1608Metric
D1, D2: D_Schottky; D_SOD-323
FL1: 0900FM15K0039; Balun_Johanson_0900FM15K0039
H1, H2: MountingHole_Pad; MountingHole_2.2mm_M2_DIN965_Pad_TopBottom
J1: USB_C_Receptacle_USB2.0_14P; USB_C_Receptacle_GCT_USB4110
J2: Conn_Coaxial; SMA_Amphenol_132289_EdgeMount
J3: Conn_01x07_Socket; PinHeader_1x07_P2.54mm_Vertical
L1: 15uH; L_0805_2012Metric
L2: 18 nH; L_0603_1608Metric
R1, R2: 5K1; R_0603_1608Metric
R4, R9, R10: 10K; R_0603_1608Metric
R5: 100R; R_0402_1005Metric
R7: 1.2K; R_0603_1608Metric
SW1: SW_SPDT; SSSS810701
U1: SX1262IMLTRT; QFN-24-1EP_4x4mm_P0.5mm_EP2.6x2.6mm
U2: TP4056-42-ESOP8; SOIC-8-1EP_3.9x4.9mm_P1.27mm_EP2.41x3.3mm_ThermalVias
U3: BGS12P2L; Infineon_PG-TSNP-6-10_0.7x1.1mm_0.7x1.1mm_P0.4mm
U4: ESP32-S3-MINI-1; ESP32-S2-MINI-1
U6: MIC5219-3.3YMM; MSOP-8_3x3mm_P0.65mm
U7: CH340X; MSOP-10_3x3mm_P0.5mm

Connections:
CHRG_BAT: BT1.1 (+), C16.2, D2.2 (A), U2.5 (BAT)
DIO2: R5.1, U1.12 (DIO2)
unnamed: D1.1 (K), D2.1 (K), SW1.2 (B)
unnamed: FL1.3 (RFI_N), U1.22 (RFI_N)
unnamed: FL1.4 (RFI_P), U1.21 (RFI_P)
unnamed: FL1.1 (RFO), L2.2, U1.23 (RFO)
unnamed: FL1.6 (SW_RFI), U3.3 (RF1)
unnamed: FL1.8 (SW_RFO), U3.1 (RF2)
unnamed: J1.A5 (CC1), R1.1
unnamed: J1.B5 (CC2), R2.2
unnamed: J2.1 (In), U3.5 (RFIN)
unnamed: C1.2, SW1.1 (A), U6.1 (EN), U6.2 (IN)
unnamed: L1.2, U1.9 (DCC_SW)
unnamed: C11.2, L1.1, U1.7 (VREG)
unnamed: C12.1, L2.1, U1.24 (VR_PA)
unnamed: R4.2, U1.15 (~RESET)
unnamed: R7.1, U2.2 (PROG)
unnamed: C13.1, R5.2, U3.6 (CTRL)
unnamed: C5.1, U6.4 (BP)
READY: U1.14 (BUSY), U4.11 (IO7)
SCR_CLK: J3.3, U4.26 (IO26)
SCR_CS: J3.7, U4.30 (IO48)
SCR_DC: J3.6, U4.29 (IO34)
SCR_MOSI: J3.4, U4.27 (IO47)
SCR_RES: J3.5, U4.28 (IO33)
SERIAL_N: U4.39 (TXD0), U7.9 (RXD)
SERIAL_P: U4.40 (RXD0), U7.8 (TXD)
SPI_CLK: U1.18 (SCK), U4.8 (IO4)
SPI_CS: U1.19 (NSS), U4.7 (IO3)
SPI_MISO: U1.17 (MOSI), U4.9 (IO5)
SPI_MOSI: U1.16 (MISO), U4.10 (IO6)
USB_DATA+: J1.A6 (D+), J1.B6 (D+), U7.1 (UD+)
USB_DATA-: J1.A7 (D-), J1.B7 (D-), U7.2 (UD-)
V+: C15.1, D1.2 (A), J1.A4 (VBUS), J1.A9 (VBUS), J1.B4 (VBUS), J1.B9 (VBUS), U2.4 (V_{CC}), U2.8 (CE)
V-: BT1.2 (-), C1.1, C2.1, C3.1, C4.1, C5.2, C6.2, C7.2, C10.2, C11.1, C12.2, C13.2, C14.1, C15.2, C16.1, C17.1, C18.1, FL1.2 (GND), FL1.5 (GND), FL1.7 (GND), FL1.9 (GND), FL1.10 (GND), H1.1 (1_1), H2.1 (1_1), J1.A1 (GND), J1.A12 (GND), J1.B1 (GND), J1.B12 (GND), J1.SH (SHIELD), J2.2 (Ext), J3.1, R1.2, R2.1, R7.2, SW1.3 (C), U1.2 (GND), U1.5 (GND), U1.8 (GND), U1.20 (GND), U1.25 (GND), U2.3 (GND), U2.9 (EPAD), U3.2 (GND), U4.1 (GND), U4.2 (GND), U4.42 (GND), U4.43 (GND), U4.46 (GND), U4.47 (GND), U4.48 (GND), U4.49 (GND), U4.50 (GND), U4.51 (GND), U4.52 (GND), U4.53 (GND), U4.54 (GND), U4.55 (GND), U4.56 (GND), U4.57 (GND), U4.58 (GND), U4.59 (GND), U4.60 (GND), U4.61 (GND), U4.62 (GND), U4.63 (GND), U4.64 (GND), U4.65 (GND), U6.5 (GND), U6.6 (GND), U6.7 (GND), U6.8 (GND), U7.3 (GND)
VCC: C2.2, C3.2, C4.2, C6.1, C7.1, C10.1, C14.2, C17.2, C18.2, J3.2, R4.1, R9.2, R10.2, U1.1 (VDD_IN), U1.10 (VBAT), U1.11 (VBAT_IO), U3.4 (VDD), U4.3 (3V3), U6.3 (OUT), U7.7 (VCC), U7.10 (V3)
~CHRG: R10.1, U2.7 (~CHRG), U4.20 (IO16)
~STDBY: R9.1, U2.6 (~STDBY), U4.21 (IO17)

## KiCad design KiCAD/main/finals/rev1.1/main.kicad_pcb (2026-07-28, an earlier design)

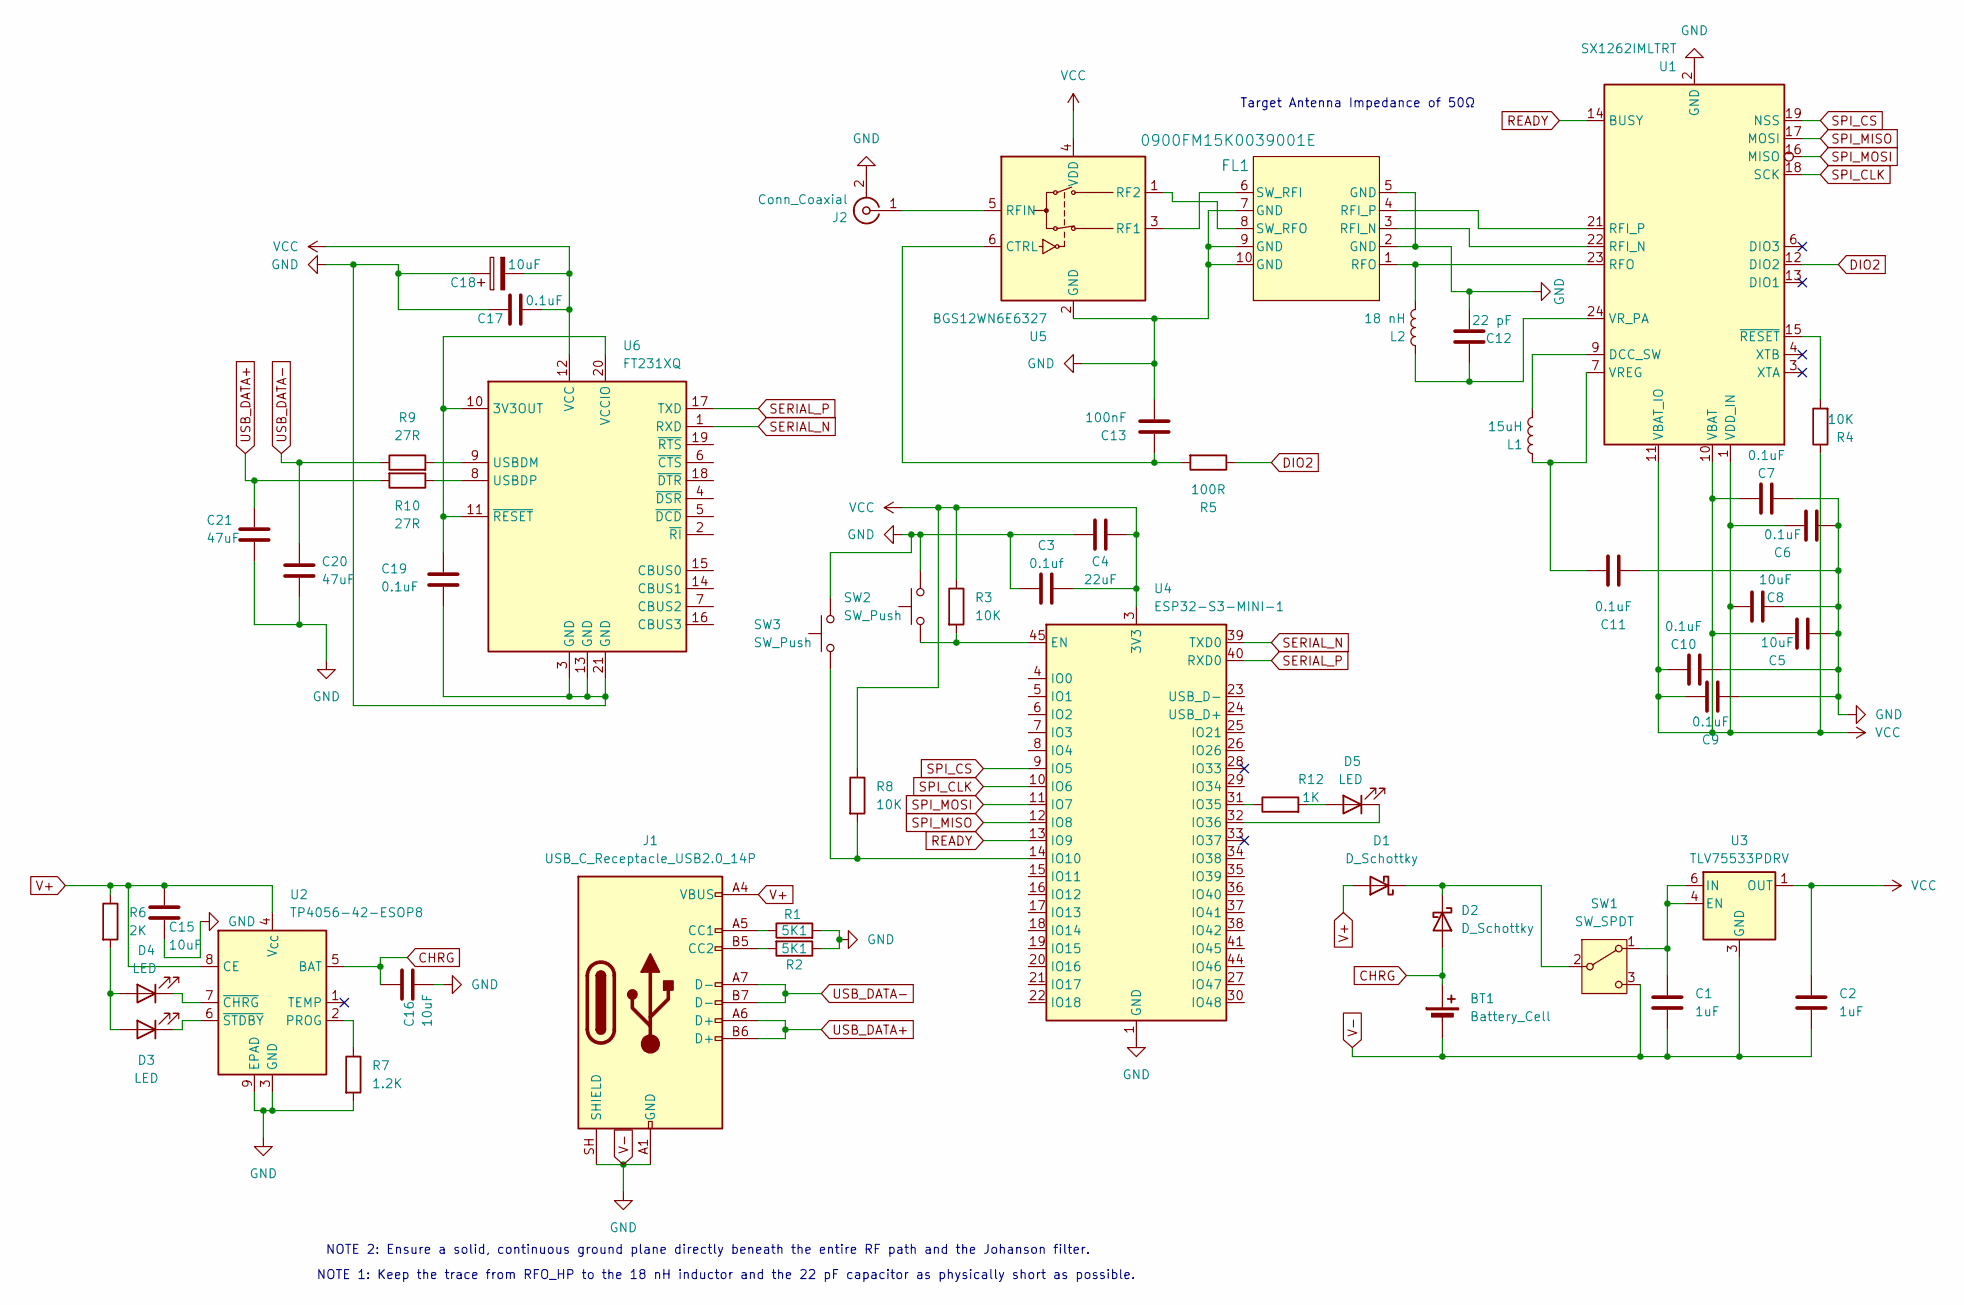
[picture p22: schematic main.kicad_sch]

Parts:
BT1: Battery_Cell; JST_PH_S2B-PH-K_1x02_P2.00mm_Horizontal
C1, C2: 1uF; C_01005_0402Metric
C3: 0.1uf; C_01005_0402Metric
C4: 22uF; C_01005_0402Metric
C5, C8, C15, C16: 10uF; C_01005_0402Metric
C6, C7, C9, C10, C11, C17, C19: 0.1uF; C_01005_0402Metric
C12: 22 pF; C_01005_0402Metric
C13: 100nF; C_01005_0402Metric
C18: 10uF; CP_EIA-1608-08_AVX-J
C20, C21: 47uF; C_01005_0402Metric
D1, D2: D_Schottky; D_01005_0402Metric
D3, D4, D5: LED; LED_0402_1005Metric
FL1: 0900FM15K0039001E; 0900FM15K0039001E_JOT-L
J1: USB_C_Receptacle_USB2.0_14P; USB_C_Receptacle_GCT_USB4110
J2: Conn_Coaxial; SMA_Amphenol_132289_EdgeMount
L1: 15uH; L_01005_0402Metric
L2: 18 nH; L_01005_0402Metric
R1, R2: 5K1; R_01005_0402Metric
R3, R4, R8: 10K; R_01005_0402Metric
R5: 100R; R_01005_0402Metric
R6: 2K; R_01005_0402Metric
R7: 1.2K; R_01005_0402Metric
R9, R10: 27R; R_01005_0402Metric
R12: 1K; R_01005_0402Metric
SW1: SW_SPDT; SW_SPDT_PCM12
SW2: SW_Push; SW_SPST_PTS810
SW3: SW_Push; SW_SPST_PTS645Sx43SMTR92
U1: SX1262IMLTRT; QFN-24-1EP_4x4mm_P0.5mm_EP2.6x2.6mm
U2: TP4056-42-ESOP8; SOIC-8-1EP_3.9x4.9mm_P1.27mm_EP2.41x3.3mm_ThermalVias
U3: TLV75533PDRV; WSON-6-1EP_2x2mm_P0.65mm_EP1x1.6mm
U4: ESP32-S3-MINI-1; ESP32-S2-MINI-1
U5: BGS12WN6E6327; Infineon_PG-TSNP-6-10_0.7x1.1mm_0.7x1.1mm_P0.4mm
U6: FT231XQ; QFN-20-1EP_4x4mm_P0.5mm_EP2.5x2.5mm

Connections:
CHRG: BT1.1 (+), C16.2, D2.2 (A), U2.5 (BAT)
DIO2: R5.1, U1.12 (DIO2)
unnamed: D1.1 (K), D2.1 (K), SW1.2 (B)
unnamed: D3.2 (A), D4.2 (A), R6.2
unnamed: D3.1 (K), U2.6 (~STDBY)
unnamed: D4.1 (K), U2.7 (~CHRG)
unnamed: D5.2 (A), R12.2
unnamed: D5.1 (K), U4.32 (IO36)
unnamed: FL1.3 (RFI_N), U1.22 (RFI_N)
unnamed: FL1.4 (RFI_P), U1.21 (RFI_P)
unnamed: FL1.1 (RFO), L2.2, U1.23 (RFO)
unnamed: FL1.6 (SW_RFI), U5.3 (RF1)
unnamed: FL1.8 (SW_RFO), U5.1 (RF2)
unnamed: J1.A5 (CC1), R1.1
unnamed: J1.B5 (CC2), R2.2
unnamed: J2.1 (In), U5.5 (RFIN)
unnamed: C1.2, SW1.1 (A), U3.4 (EN), U3.6 (IN)
unnamed: L1.2, U1.9 (DCC_SW)
unnamed: C11.2, L1.1, U1.7 (VREG)
unnamed: C12.1, L2.1, U1.24 (VR_PA)
unnamed: R4.2, U1.15 (~RESET)
unnamed: R7.1, U2.2 (PROG)
unnamed: R3.2, SW2.1, U4.45 (EN)
unnamed: R8.2, SW3.1, U4.14 (IO10)
unnamed: R12.1, U4.31 (IO35)
unnamed: C13.1, R5.2, U5.6 (CTRL)
unnamed: C19.2, U6.10 (3V3OUT), U6.11 (~RESET), U6.20 (VCCIO)
unnamed: R9.2, U6.9 (USBDM)
unnamed: R10.1, U6.8 (USBDP)
READY: U1.14 (BUSY), U4.13 (IO9)
SERIAL_N: U4.39 (TXD0), U6.1 (RXD)
SERIAL_P: U4.40 (RXD0), U6.17 (TXD)
SPI_CLK: U1.18 (SCK), U4.10 (IO6)
SPI_CS: U1.19 (NSS), U4.9 (IO5)
SPI_MISO: U1.17 (MOSI), U4.12 (IO8)
SPI_MOSI: U1.16 (MISO), U4.11 (IO7)
USB_DATA+: C21.1, J1.A6 (D+), J1.B6 (D+), R10.2
USB_DATA-: C20.1, J1.A7 (D-), J1.B7 (D-), R9.1
V+: C15.1, D1.2 (A), J1.A4 (VBUS), J1.A9 (VBUS), J1.B4 (VBUS), J1.B9 (VBUS), R6.1, U2.4 (V_{CC}), U2.8 (CE)
V-: BT1.2 (-), C1.1, C2.1, C3.1, C4.1, C5.2, C6.2, C7.2, C8.2, C9.2, C10.2, C11.1, C12.2, C13.2, C15.2, C16.1, C17.1, C18.1, C19.1, C20.2, C21.2, FL1.2 (GND), FL1.5 (GND), FL1.7 (GND), FL1.9 (GND), FL1.10 (GND), J1.A1 (GND), J1.A12 (GND), J1.B1 (GND), J1.B12 (GND), J1.SH (SHIELD), J2.2 (Ext), R1.2, R2.1, R7.2, SW1.3 (C), SW2.2, SW3.2, U1.2 (GND), U1.5 (GND), U1.8 (GND), U1.20 (GND), U1.25 (GND), U2.3 (GND), U2.9 (EPAD), U3.3 (GND), U3.7 (GND), U4.1 (GND), U4.2 (GND), U4.42 (GND), U4.43 (GND), U4.46 (GND), U4.47 (GND), U4.48 (GND), U4.49 (GND), U4.50 (GND), U4.51 (GND), U4.52 (GND), U4.53 (GND), U4.54 (GND), U4.55 (GND), U4.56 (GND), U4.57 (GND), U4.58 (GND), U4.59 (GND), U4.60 (GND), U4.61 (GND), U4.62 (GND), U4.63 (GND), U4.64 (GND), U4.65 (GND), U5.2 (GND), U6.3 (GND), U6.13 (GND), U6.21 (GND)
VCC: C2.2, C3.2, C4.2, C5.1, C6.1, C7.1, C8.1, C9.1, C10.1, C17.2, C18.2, R3.1, R4.1, R8.1, U1.1 (VDD_IN), U1.10 (VBAT), U1.11 (VBAT_IO), U3.1 (OUT), U4.3 (3V3), U5.4 (VDD), U6.12 (VCC)

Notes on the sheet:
NOTE 1: Keep the trace from RFO_HP to the 18 nH inductor and the 22 pF capacitor as physically short as possible.
NOTE 2: Ensure a solid, continuous ground plane directly beneath the entire RF path and the Johanson filter.
Target Antenna Impedance of 50Ω

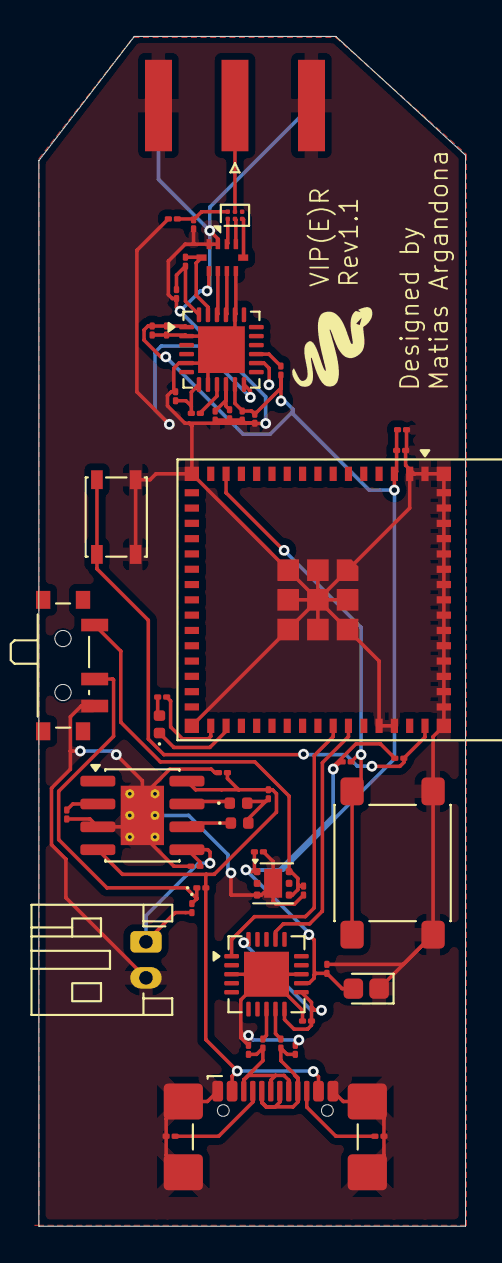
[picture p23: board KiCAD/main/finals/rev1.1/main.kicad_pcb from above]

Board: 2 copper layers, 23.7 x 66.1 mm, 51 parts (0 on the bottom side), 41 nets.

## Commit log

2026-07-03 started schematic and PCB
    [SX1262MB2IPDDAS_868-915MHz_e588v01a_Murata_BOM.xlsx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]
2026-07-06 started repo and creation
    [901-10040-1.SchLib, 901-10040-1.stp, 901100401.PcbLib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]
2026-07-06 finished rev1.2 and started JOURNAL
    [main.kicad_pcb, main.kicad_sch]
2026-07-28 rev 2!
    [main.kicad_pcb, main.kicad_sch]
2026-07-30 added screen to rev 2 and bumped version to 2.1
    [bom.csv, designators.csv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]
